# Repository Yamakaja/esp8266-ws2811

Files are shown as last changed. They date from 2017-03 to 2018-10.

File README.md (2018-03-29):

# ESP8266-WS2811

## Requirements

* Linux (I've not tried other environments)
* The [esp-open-sdk](https://github.com/pfalcon/esp-open-sdk)
* An environment variable "ESP_ROOT" pointing to the root of the above sdk
* An addition to the `PATH` environment variable, pointing into `$ESP_ROOT/xtensa-lx106-elf/bin/`

## Setup

* Copy the user_config.h.template header to user_config.h (Within the `include/` directory) and enter your SSID and password.
* Get your hardware setup - the signal will be sent to the uart RX pin - see the KiCad project and schematic in `pcb/` for more information.
* Connect your ESP and find out which port it is connected to.
* Get your ESP ready for flashing over UART
* Comile and flash by running `make flash PORT=<esp>`, where `<esp>` would usually be something like `/dev/ttyUSB0`

## The protocol

You can then control the led strip by sending UDP packets with the following format:

    [Packet] 	:= [LED] * ledCount
    [LED]		:= [r: byte][g: byte][b: byte]

##### Example:

Set the first driver to magenta:

```java
byte[] packet = new byte[]{0xFF, 0x00, 0xFF};
```

## Timing

More timing information can be found in the [Timing](Timing) file

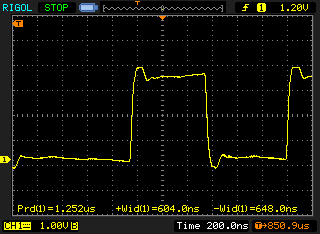
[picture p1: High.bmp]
High


©2017 Yamakaja

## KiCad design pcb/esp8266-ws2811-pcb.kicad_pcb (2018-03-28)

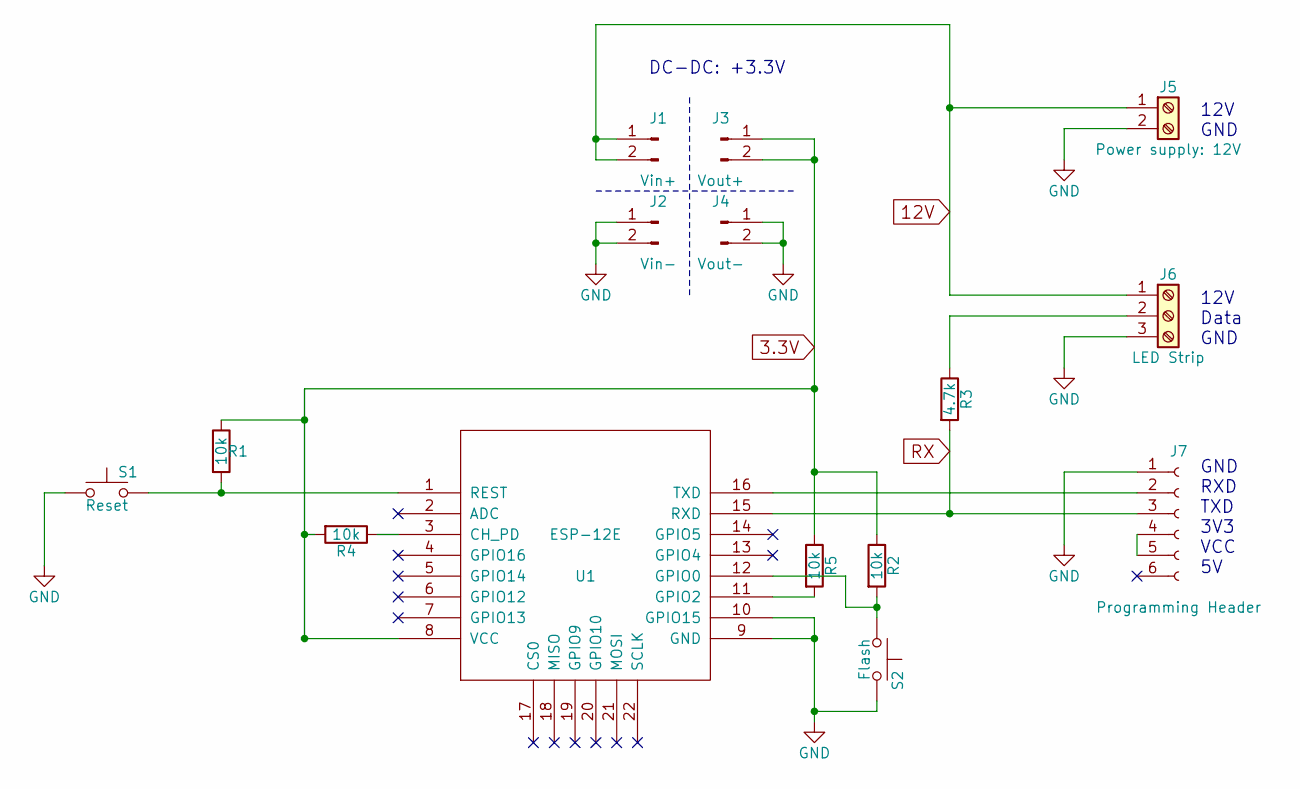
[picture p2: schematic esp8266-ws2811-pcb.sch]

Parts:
J1: Vin+; Pin_Header_Straight_1x02_Pitch2.54mm
J2: Vin-; Pin_Header_Straight_1x02_Pitch2.54mm
J3: Vout+; Pin_Header_Straight_1x02_Pitch2.54mm
J4: Vout-; Pin_Header_Straight_1x02_Pitch2.54mm
J5: Power supply: 12V; TerminalBlock_bornier-2_P5.08mm
J6: LED Strip; TerminalBlock_bornier-3_P5.08mm
J7: Programming Header; Socket_Strip_Straight_1x06_Pitch2.54mm
R1, R2, R4, R5: 10k; R_Axial_DIN0207_L6.3mm_D2.5mm_P7.62mm_Horizontal
R3: 4.7k; R_Axial_DIN0207_L6.3mm_D2.5mm_P7.62mm_Horizontal
S1: Reset; SW_PUSH_6mm_h7.3mm
S2: Flash; SW_PUSH_6mm_h7.3mm
U1: ESP-12E

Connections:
3.3V: J3.1, J3.2, R1.1, R2.1, R4.2, R5.1, U1.8 (VCC)
12V: J1.1, J1.2, J5.1, J6.1
GND: J2.1, J2.2, J4.1, J4.2, J5.2, J6.3, J7.1, S1.1, S2.2, U1.9 (GND), U1.10 (GPIO15)
unnamed: J6.2, R3.1
unnamed: J7.2, U1.16 (TXD)
unnamed: J7.4, J7.5
unnamed: R1.2, S1.2, U1.1 (REST)
unnamed: R2.2, S2.1, U1.12 (GPIO0)
unnamed: R4.1, U1.3 (CH_PD)
unnamed: R5.2, U1.11 (GPIO2)
RX: J7.3, R3.2, U1.15 (RXD)

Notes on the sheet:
GND RXD TXD 3V3 VCC 5V
DC-DC: +3.3V
12V Data GND
12V GND

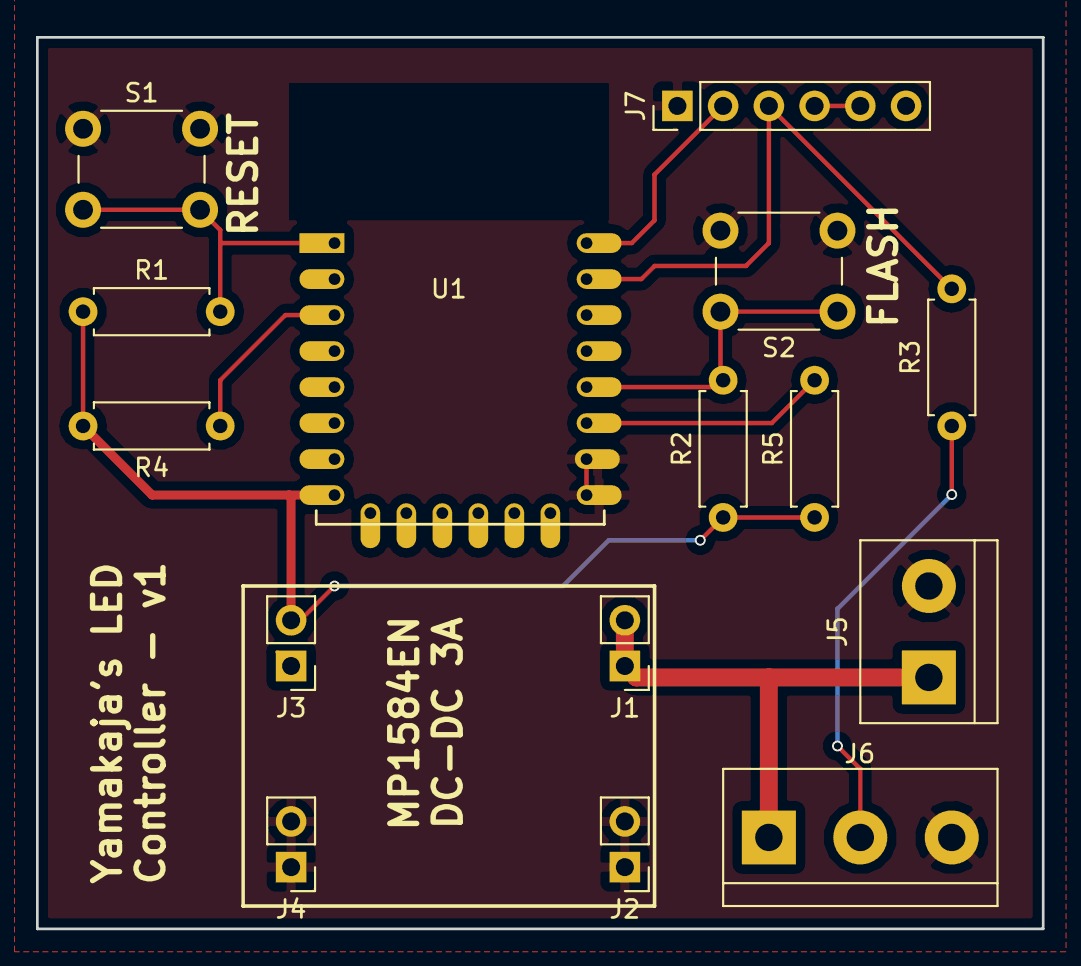
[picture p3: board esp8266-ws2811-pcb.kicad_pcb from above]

Board: 2 copper layers, 55.9 x 49.5 mm, 15 parts (0 on the bottom side), 11 nets.

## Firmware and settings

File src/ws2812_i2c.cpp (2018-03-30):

/******************************************************************************
 * Copyright 2013-2015 Espressif Systems
 *           2015 <>< Charles Lohr
 *           2018 Yamakaja
 *
 * FileName: ws2811_i2c.c
 *
 * Description: I2S output routines for a FreeRTOS system. Uses DMA and a queue
 * to abstract away the nitty-gritty details.
 *
 * Modification history:
 *     2015/06/01, v1.0 File created.
 *     2015/07/23, Switch to making it a WS2812 output device.
*******************************************************************************
Notes:
 This is pretty badly hacked together from the MP3 example.
 I spent some time trying to strip it down to avoid a lot of the TX_ stuff. 
 That seems to work.
 Major suggestions that I couldn't figure out:
    * Use interrupts to disable DMA, so it isn't running nonstop.
    * Use interrupts to flag when new data can be sent.
 When I try using interrupts, it seems to work for a bit but things fall apart
 rather quickly and the engine just refuses to send anymore until reboot.
 The way it works right now is to keep the DMA running forever and just update
 the data in the buffer so it continues sending the frame.
Extra copyright info:
  Actually not much of this file is Copyright Espressif, comparativly little
  mostly just the stuff to make the I2S bus go.
*******************************************************************************/

extern "C" void rom_i2c_writeReg_Mask(int, int, int, int, int, int);

#include "driver/slc_register.h"
#include "i2s_reg.h"
#include "pin_mux_register.h"
#include "user_interface.h"
#include "ws2812_i2c.h"
#include <c_types.h>

// Creates an I2S SR of 93,750 Hz, or 3 MHz Bitclock (.333us/sample)
// 1600000000L/(div*bestbck)
// It is likely you could speed this up a little.

#define WS_I2S_BCK 21 // Seems to work as low as 18, but is shakey at 1.
#define WS_I2S_DIV 3

#ifndef i2c_bbpll
#define i2c_bbpll 0x67
#define i2c_bbpll_en_audio_clock_out 4
#define i2c_bbpll_en_audio_clock_out_msb 7
#define i2c_bbpll_en_audio_clock_out_lsb 7
#define i2c_bbpll_hostid 4

#define i2c_writeReg_Mask(block, host_id, reg_add, Msb, Lsb, indata)           \
  rom_i2c_writeReg_Mask(block, host_id, reg_add, Msb, Lsb, indata)
#define i2c_readReg_Mask(block, host_id, reg_add, Msb, Lsb)                    \
  rom_i2c_readReg_Mask(block, host_id, reg_add, Msb, Lsb)
#define i2c_writeReg_Mask_def(block, reg_add, indata)                          \
  i2c_writeReg_Mask(block, block##_hostid, reg_add, reg_add##_msb,             \
                    reg_add##_lsb, indata)
#define i2c_readReg_Mask_def(block, reg_add)                                   \
  i2c_readReg_Mask(block, block##_hostid, reg_add, reg_add##_msb, reg_add##_lsb)
#endif
#ifndef ETS_SLC_INUM
#define ETS_SLC_INUM 1
#endif


//From sdio_slv.h
struct sdio_queue {
  uint32 blocksize : 12;
  uint32 datalen : 12;
  uint32 unused : 5;
  uint32 sub_sof : 1;
  uint32 eof : 1;
  uint32 owner : 1;

  uint32 buf_ptr;
  uint32 next_link_ptr;
};

// Rest of program...

// I2S DMA buffer descriptors
static struct sdio_queue i2sBufDescOut;
static struct sdio_queue i2sBufDescZeroes;

static uint8_t i2sZeroes[128];
static uint8_t i2sBlock[WS_BLOCKSIZE];

//Initialize I2S subsystem for DMA circular buffer use
void ICACHE_FLASH_ATTR ws2812_init() {
    // Reset DMA
    SET_PERI_REG_MASK(SLC_CONF0, SLC_RXLINK_RST);
    CLEAR_PERI_REG_MASK(SLC_CONF0, SLC_RXLINK_RST);
  
    // Clear DMA int flags
    SET_PERI_REG_MASK(SLC_INT_CLR, 0xffffffff);
    CLEAR_PERI_REG_MASK(SLC_INT_CLR, 0xffffffff);
  
    // Enable and configure DMA
    CLEAR_PERI_REG_MASK(SLC_CONF0, (SLC_MODE << SLC_MODE_S));
    SET_PERI_REG_MASK(SLC_CONF0, (1 << SLC_MODE_S));
    SET_PERI_REG_MASK(SLC_RX_DSCR_CONF, SLC_INFOR_NO_REPLACE | SLC_TOKEN_NO_REPLACE);
    CLEAR_PERI_REG_MASK(SLC_RX_DSCR_CONF, SLC_RX_FILL_EN | SLC_RX_EOF_MODE | SLC_RX_FILL_MODE);
  
    i2sBufDescOut.owner = 1; // Software owned
    i2sBufDescOut.eof = 1;
    i2sBufDescOut.sub_sof = 0;
    i2sBufDescOut.datalen = WS_BLOCKSIZE;   // Size (in bytes)
    i2sBufDescOut.blocksize = WS_BLOCKSIZE; // Size (in bytes)
    i2sBufDescOut.buf_ptr = (uint32_t) i2sBlock;
    i2sBufDescOut.unused = 0;
    // At the end, just redirect the DMA to the zero buffer.
    i2sBufDescOut.next_link_ptr = (uint32_t) &i2sBufDescZeroes;

    i2sBufDescZeroes.owner = 1;
    i2sBufDescZeroes.eof = 1;
    i2sBufDescZeroes.sub_sof = 0;
    i2sBufDescZeroes.datalen = 32;
    i2sBufDescZeroes.blocksize = 32;
    i2sBufDescZeroes.buf_ptr = (uint32_t)i2sZeroes;
    i2sBufDescZeroes.unused = 0;
    i2sBufDescZeroes.next_link_ptr = (uint32_t) &i2sBufDescOut;
  
    for (int x = 0; x < sizeof(i2sZeroes); x++)
      i2sZeroes[x] = 0x00;
  
    for (int x = 0; x < WS_BLOCKSIZE; x++)
      i2sBlock[x] = 0x00;
  
    CLEAR_PERI_REG_MASK(SLC_RX_LINK, SLC_RXLINK_DESCADDR_MASK);
    SET_PERI_REG_MASK(SLC_RX_LINK, ((uint32_t)&i2sBufDescOut) & SLC_RXLINK_DESCADDR_MASK);
  
    // Start transmission
    SET_PERI_REG_MASK(SLC_RX_LINK, SLC_RXLINK_START);
  
    //----
  
    PIN_FUNC_SELECT(PERIPHS_IO_MUX_U0RXD_U, FUNC_I2SO_DATA);
  
    // Enable clock to i2s subsystem
    i2c_writeReg_Mask_def(i2c_bbpll, i2c_bbpll_en_audio_clock_out, 1);
  
    // Reset I2S subsystem
    CLEAR_PERI_REG_MASK(I2SCONF, I2S_I2S_RESET_MASK);
    SET_PERI_REG_MASK(I2SCONF, I2S_I2S_RESET_MASK);
    CLEAR_PERI_REG_MASK(I2SCONF, I2S_I2S_RESET_MASK);
  
    // Select 16 bits per channel (FIFO_MOD=0), no DMA access (FIFO only)
    CLEAR_PERI_REG_MASK(I2S_FIFO_CONF, I2S_I2S_DSCR_EN |
                            (I2S_I2S_RX_FIFO_MOD << I2S_I2S_RX_FIFO_MOD_S) |
                            (I2S_I2S_TX_FIFO_MOD << I2S_I2S_TX_FIFO_MOD_S));
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

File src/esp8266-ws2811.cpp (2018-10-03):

extern "C" {
    #include "osapi.h"
    #include "driver/uart.h"
    #include "user_interface.h"
    #include "espconn.h"
}

#include "user_config.h"
#include "ws2812_i2c.h"

namespace {
    const char ssid[] = SSID;
    const char psk[] = PSK;

    esp_udp udp;
    espconn connection;
}

void ICACHE_FLASH_ATTR setupWiFi() {
    wifi_set_opmode(0x1);

    station_config config;

    config.bssid_set = 0;

    os_memcpy(&config.ssid, ssid, sizeof(ssid));
    os_memcpy(&config.password, psk, sizeof(psk));
    os_printf("wifi_station_set_config() -> %d\n", wifi_station_set_config(&config));

    wifi_station_set_auto_connect(true);
}

void udp_recv_callback(void *arg, char *pdata, unsigned short len) {
    ws2812_push(reinterpret_cast<uint8_t*>(pdata), len);
}

void ICACHE_FLASH_ATTR setupUdpServer() {
    udp.local_port = 1234;
    connection.type = ESPCONN_UDP;
    connection.state = ESPCONN_NONE;
    connection.proto.udp = &udp;

    switch (espconn_create(&connection)) {
        case 0:
            os_printf("%d: Created server!\n", __LINE__);
            break;
        case ESPCONN_ISCONN:
            os_printf("%d: Already connected!\n", __LINE__);
            return;
        case ESPCONN_MEM:
            os_printf("%d: Out of memory!\n", __LINE__);
            return;
        case ESPCONN_ARG:
            os_printf("%d: Illegal argumenet!\n", __LINE__);
            return;
    }

    if (espconn_regist_recvcb(&connection, udp_recv_callback)) {
        os_printf("Unknown connection!\n");
        return;
    }
}

extern "C" void ICACHE_FLASH_ATTR user_init() {
    // configure UART TXD to be GPIO1, set as output
    PIN_FUNC_SELECT(PERIPHS_IO_MUX_U0TXD_U, FUNC_GPIO1);

    uart_init(BIT_RATE_115200, BIT_RATE_115200);

    setupWiFi();
    setupUdpServer();

    ws2812_init();
}

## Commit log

2018-03-28 Add PCB
    [esp8266-ws2811-pcb-B.Cu.gbr, esp8266-ws2811-pcb-B.Mask.gbr, esp8266-ws2811-pcb-B.SilkS.gbr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]
2018-03-29 Switch to esp-open-sdk; Use I2C DMA

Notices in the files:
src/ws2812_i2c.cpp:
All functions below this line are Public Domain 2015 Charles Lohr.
